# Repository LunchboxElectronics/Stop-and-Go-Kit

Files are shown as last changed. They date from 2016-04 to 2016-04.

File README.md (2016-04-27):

# README #

Stop and Go Kit by Lunchbox Electronics. 2015

### What is this repository for? ###

This repo supplies instructions and source files to create and make derivatives of the Stop and Go Kit. This kit is programmed to be a simple stoplight with an ATtiny and Build Upons PTH Edition. Compatible with LEGO sets. This repo contains:

* Eagle Files
* Instructions
* Gif

### How do I get set up? ###

* Code is written in Arduino
* Board File and Schematic are created in Eagle

### Licensing ###
Stop and Go kit is an open source hardware product and follows the open source hardware definition: www.oshwa.org/definition The Eagle Files are licensed CC-BY-SA: Lunchbox Electronics.

### Warrenty ###
Distributed as-is; no warranty given. Not suitable for people who might eat electronics.

### Who do I talk to? ###

* Created by Jason Brownstein @ Lunchbox Electronics 5/6/15
* Contact contact@lunchboxelectronics.com

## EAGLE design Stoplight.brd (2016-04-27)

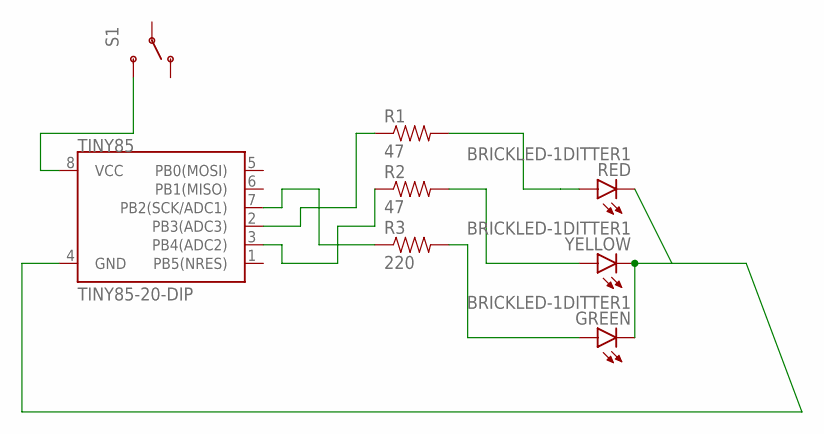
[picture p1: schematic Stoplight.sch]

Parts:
GREEN: BRICKLED-1DITTER1; BRICKLED-1DITTER
R1, R2: 47; AXIAL-0.3
R3: 220; AXIAL-0.3
RED: BRICKLED-1DITTER1; BRICKLED-1DITTER
S1: SWITCH-SPDTKIT; SWITCH-SPDT_KIT
TINY85: TINY85-20-DIP; DIP08
YELLOW: BRICKLED-1DITTER1; BRICKLED-1DITTER

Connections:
unnamed: S1.3 (S), TINY85.8 (VCC)
unnamed: R1.P$2 (2), RED.A
unnamed: GREEN.K (C), RED.K (C), TINY85.4 (GND), YELLOW.K (C)
unnamed: R1.P$1 (1), TINY85.2 (PB3(ADC3))
unnamed: R2.P$1 (1), TINY85.3 (PB4(ADC2))
unnamed: GREEN.A, R3.P$2 (2)
unnamed: R2.P$2 (2), YELLOW.A
unnamed: R3.P$1 (1), TINY85.7 (PB2(SCK/ADC1))

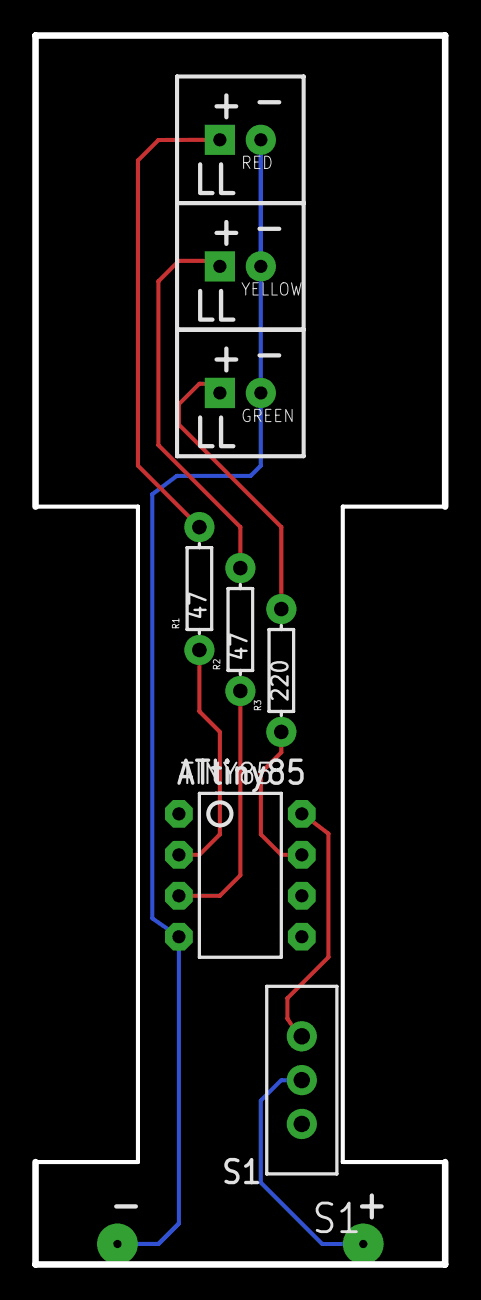
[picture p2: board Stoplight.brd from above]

Board: 2 copper layers, 25.4 x 76.2 mm, 8 parts (0 on the bottom side), 8 nets.

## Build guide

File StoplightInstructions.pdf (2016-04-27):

## Stop and Go Kit Assembly Guide

## Stop and Go kit contains:

3 Build Upons PTH LEDs
1 ATtiny85
1 220 ohm resistor
2 47 ohm resistors

1 switch
1 3V battery
1 battery holder

## Tools you will need:

Soldering Iron
Solder
Wire Snips

LBE LunchboxElectronics.com

## Assembly:

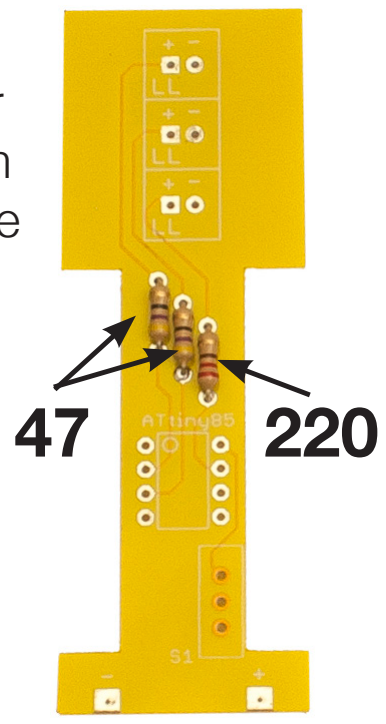
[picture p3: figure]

Step 1: Solder
in the 220 ohm
resistor and the
two 47 ohm
resistors.
Step 2: Solder in the

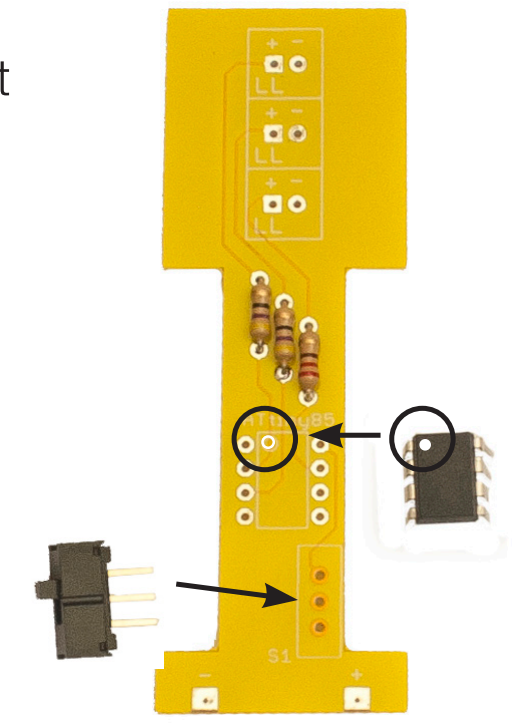
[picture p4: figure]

ATtiny chip. The tiny dot
on one side of the chip
should match up with
the dot on the board.
Step 3: Solder in the
switch. The direction
does not matter.

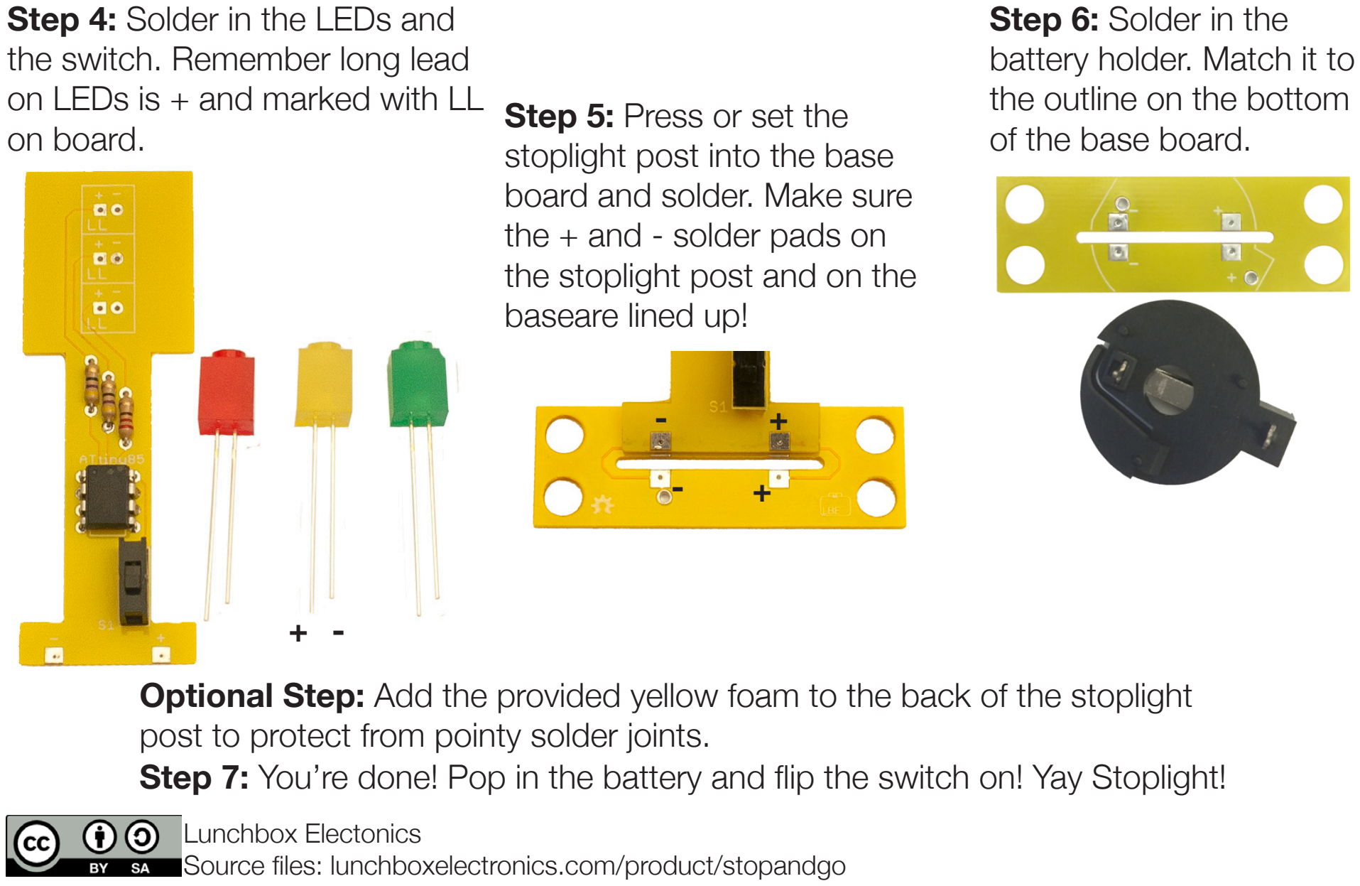
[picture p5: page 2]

Step 4: Solder in the LEDs and the switch. Remember long lead on LEDs is + and marked with LL on board.

+ -

Step 5: Press or set the
stoplight post into the base board and solder. Make sure the + and - solder pads on the stoplight post and on the baseare lined up!
Step 6: Solder in the
battery holder. Match it to the outline on the bottom
of the base board.
- +
Step 7: You’re done! Pop in the battery and flip the switch on! Yay Stoplight!
Lunchbox Electonics
Source files: lunchboxelectronics.com/product/stopandgo
- +

Optional Step: Add the provided yellow foam to the back of the stoplight post to protect from pointy solder joints.

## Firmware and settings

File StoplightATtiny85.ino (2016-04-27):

//Programmed using ATtiny85 (internal 1MHz clock) on USBtinyISP

void setup(){
  pinMode(3,OUTPUT); //RED
  pinMode(4,OUTPUT); //YELLOW
  pinMode(2,OUTPUT); //GREEN
}

void loop(){
  digitalWrite(2,HIGH); //Turn GREEN on
  delay(2000);          //Wait for 2 seconds
  digitalWrite(2,LOW);  //Turn GREEN off
  
  digitalWrite(4,HIGH); //Turn YELLOW on
  delay(1000);          //Wait for 1 seconds
  digitalWrite(4,LOW);  //Turn YELLOW off
  
  digitalWrite(3,HIGH); //Turn RED on
  delay(2000);          //Wait for 2 seconds
  digitalWrite(3,LOW);  //Turn RED off
}

  
  

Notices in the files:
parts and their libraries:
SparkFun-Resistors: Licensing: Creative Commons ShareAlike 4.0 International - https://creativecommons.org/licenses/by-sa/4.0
